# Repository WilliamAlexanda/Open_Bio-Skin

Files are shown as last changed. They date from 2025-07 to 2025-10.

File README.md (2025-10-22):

# Bio-Skin multi-modal tactile sensor

Nice to see you here!

This document will help you to know how to make your own Bio-Skin tactile sensor. If you still don't know what is Bio-Skin, please check our project homepage for more detail: https://williamalexanda.github.io/Bio-Skin/

## About the open source

Hardware of Bio-Skin will be open sourced under the Creative Commons Attribution-NonCommercial 4.0 International License, which means it's open for personal NonCommercial usage only.

Hardware parts include all molds, materials list and code for Esp32. Without software in PC, you can still get the sensor raw data by following this tutorial: https://youtu.be/GShOp8S6hr8

If you want the software which includes super-resolution or GUI or have any other questions, please send a email(haoran.guo@okstate.edu) to get more information.

中文制作教程：https://www.bilibili.com/video/BV1KD8Tz4ERr/
## Open Source List
Hardware folder: including all molds, Sensor PCB and single MUX PCB. All electronic components are directly marked in the figure.

Software folder: The code for ESP32-S3, which includes control, sample and data transmission function.

Material list: All the material you need to make the Bio-Skin.

## License

This project is released under a split licensing model to ensure both the hardware designs and the software code remain open and reciprocal.

| Component | License | Copyleft Strength | Full Text |
| :--- | :--- | :--- | :--- |
| **Hardware Designs** (Schematics, PCB, CAD files) | **CERN Open Hardware Licence v2.0 - Strongly Reciprocal (CERN-OHL-S 2.0)** | Strong | [LICENSE-HARDWARE](./LICENSE-HARDWARE) |
| **Software** (Firmware, Control Code) | **GNU Affero General Public License v3.0 (AGPLv3)** | Strong (Network Usage) | [LICENSE-SOFTWARE](./LICENSE-SOFTWARE) |

**CERN-OHL-S 2.0:** Requires that any modifications to the hardware design files must also be shared under the same license.

**AGPLv3:** Requires that any changes to the software, even if used only as a network service, must have their source code made available to users.

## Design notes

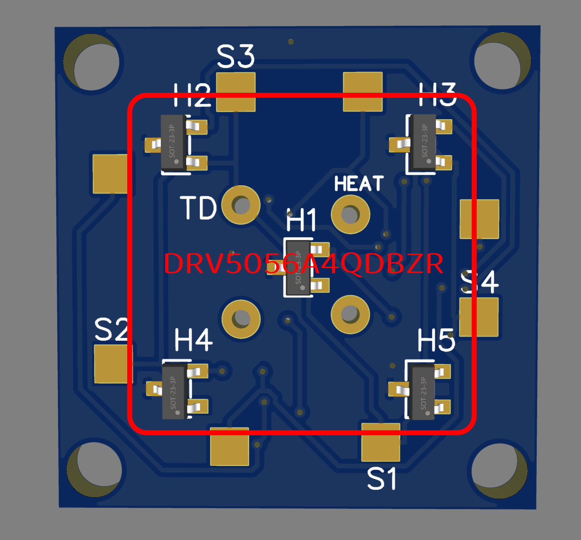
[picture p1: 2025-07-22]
Hardware/PCB/Main board/屏幕截图 2025-07-19 204715.jpg

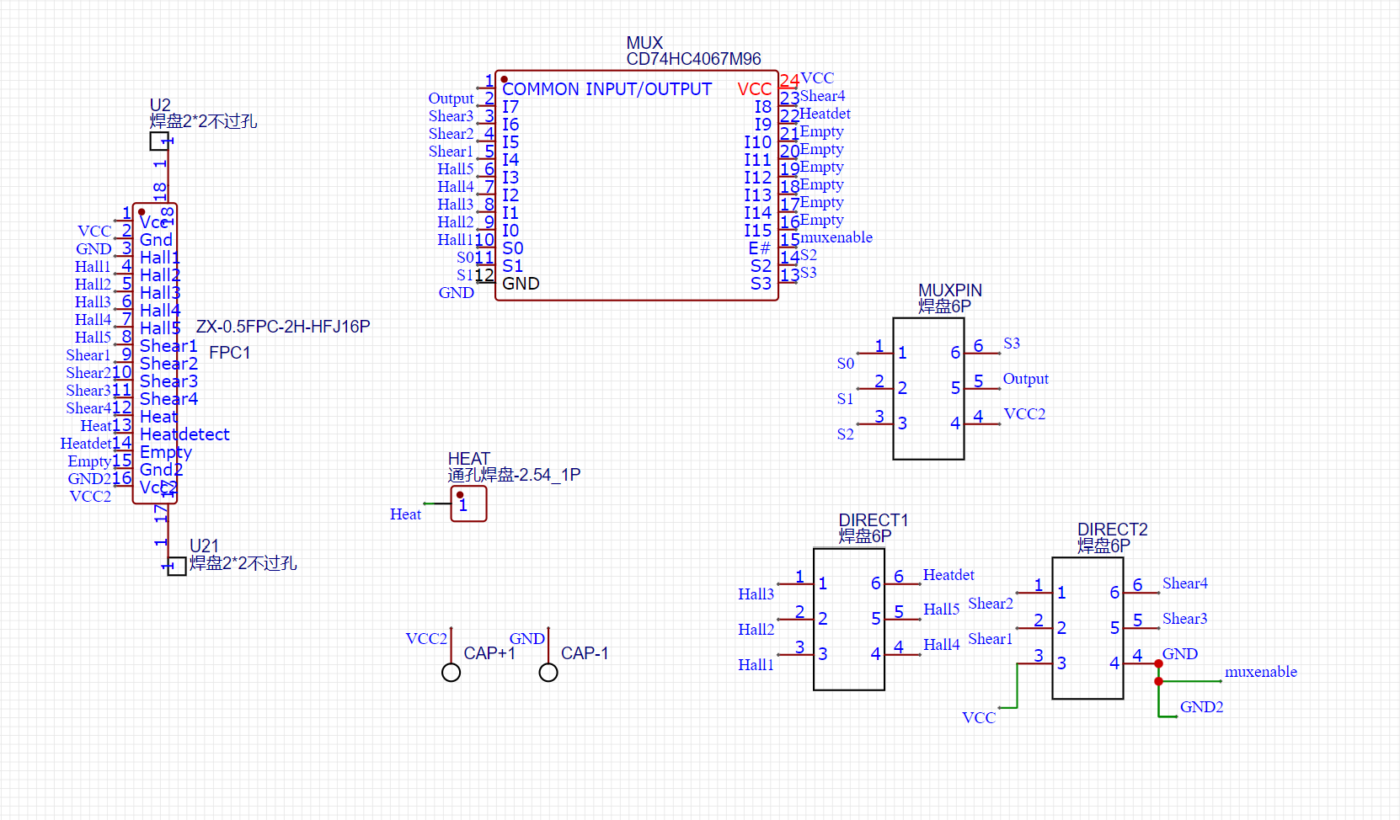
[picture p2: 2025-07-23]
Hardware/PCB/Little board/屏幕截图 2025-07-23 172235.png

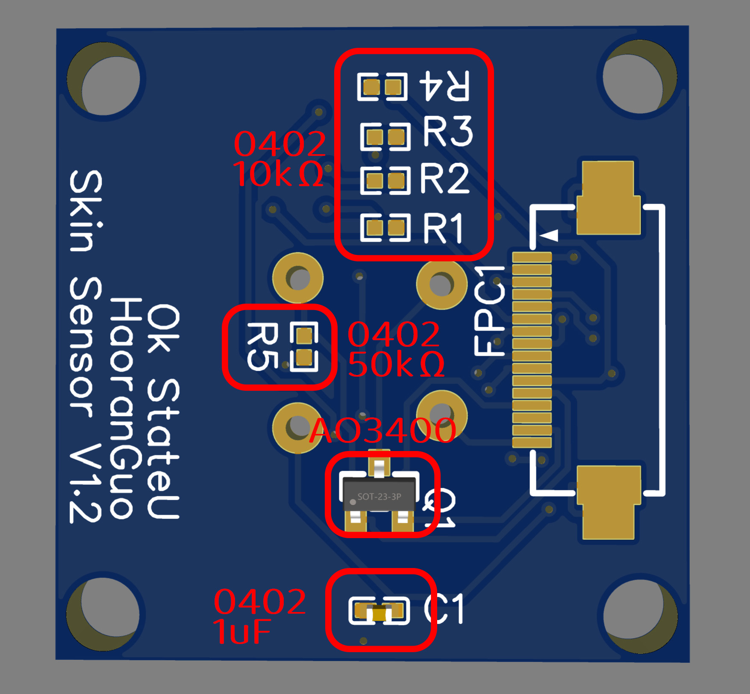
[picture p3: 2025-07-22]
Hardware/PCB/Main board/屏幕截图 2025-07-19 204727.jpg

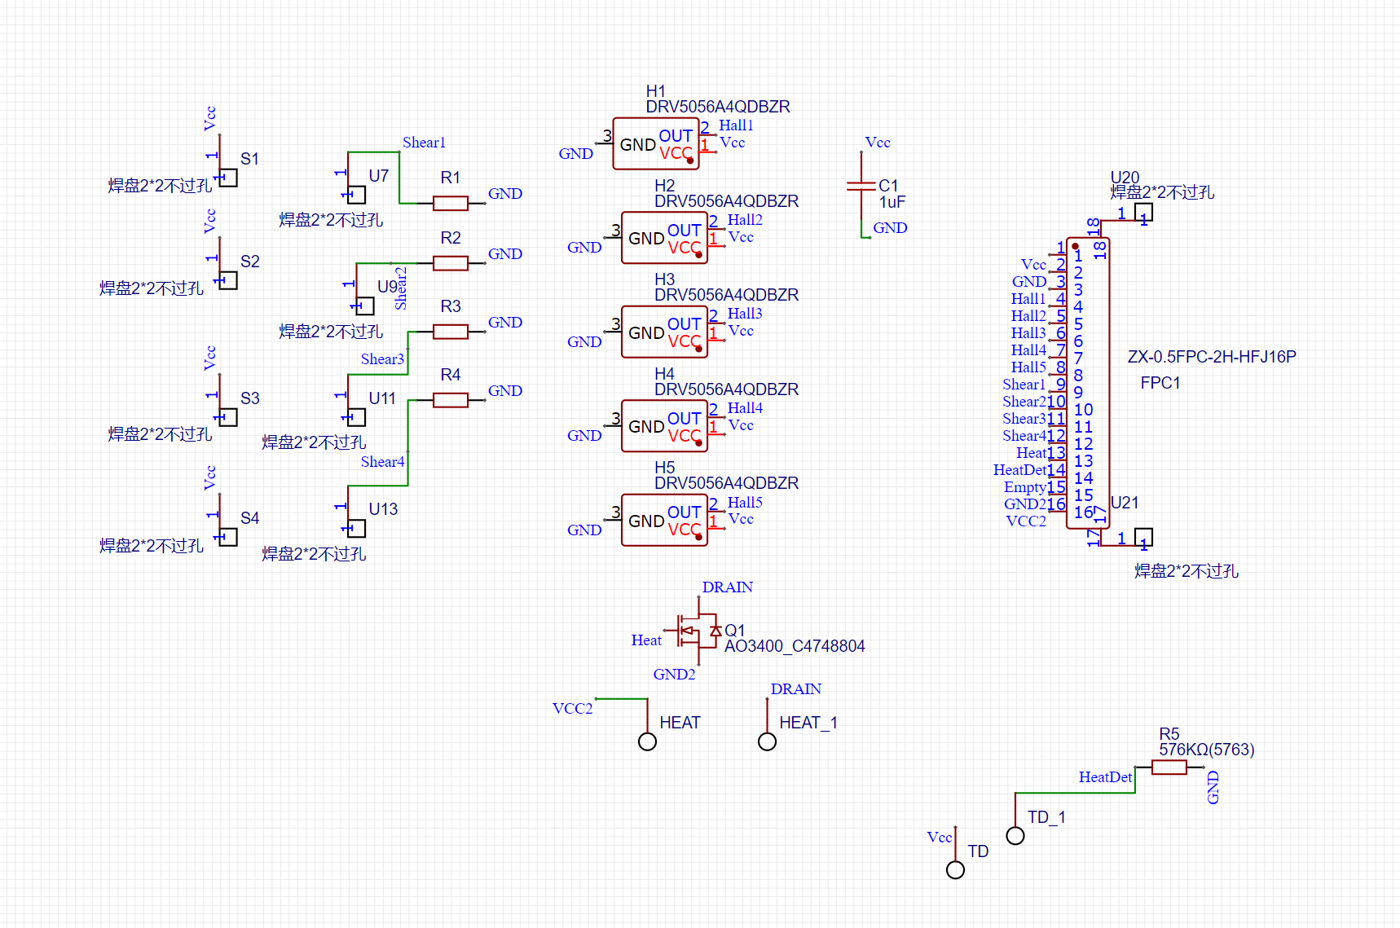
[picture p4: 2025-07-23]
Hardware/PCB/Main board/Design Sheet.png

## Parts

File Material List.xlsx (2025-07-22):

Name | Amount | type | price | discribe | Shop | Total | Link
PDMS-1 | 1 | Dragon Skin 10 Fast | 39.1 |  | Amazon | 39.1 | https://www.amazon.com/dp/B00IFI7G2E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
Hall-effect sensor | >=5 | DRV5056A4QDBZR | 0.22 |  | TEXAS Instrument |  | https://www.ti.com/product/DRV5056#params
meganetic | 1 | combo size | 9.99 |  | Amazon | 9.99 | https://www.amazon.com/TRYMAG-Magnets-Different-Miniatures-Refrigerator/dp/B0BLSLZ8JN?s=industrial
ESP32-S3 | >=1
Spring | >=4 |  |  | #VALUE!
Resistance Heating Coils Resistor Wire | 1 |  | 5.95 |  | Amazon | 5.95 | https://www.amazon.com/US-SA-AJD-144156-Nichrome-Resistance-Heating-Resistor/dp/B019MNNRN2?s=industrial
Pressure Sensitity film | 1 |  | 4.95 |  |  |  | https://www.adafruit.com/product/1361
Enameled Copper Wire | 1 |  | 12.29 |  | Amazon |  | https://www.amazon.com/BNTECHGO-AWG-Magnet-Wire-Transformers/dp/B07GBMKMKY?sp_csd=d2lkZ2V0TmFtZT1zcF9hdGY
NTC Thermistors Resistors | 1 |  | 11.99 |  | Amazon |  | https://www.amazon.com/KOKISO-Thermistors-Resistors-Temperature-Assortment/dp/B09LSCXN32
Conductive Nylon Conductive Adhesive Tape | 1 |  | 10 |  | Amazon |  | https://www.amazon.com/0-2in-Conductive-Nylon-Adhesive-Circuits/dp/B0BP1BNYR6?sp_csd=d2lkZ2V0TmFtZT1zcF9hdGY
FPC SLOT | >=5 | 16pin
FPC | >=1 | 16pin (opposite pin face)
0402 residtor | 1 |  | 7.99 |  |  |  | https://www.amazon.com/Yobett-3250PCS-Resistor-Tolerance-Resistors/dp/B0BZGQ8136
0402 capacitor | 1 | 1200pcs | 8.49 |  |  |  | https://www.amazon.com/Cermant-Capacitor-Assorted-1pF-10uF-Electronic/dp/B09V9WD8S6
Surgical Grade Blades | 1 |  | 6.99 |  |  |  | https://www.amazon.com/Surgical-Sterile-Practicing-Sculpting-Repairing/dp/B07WTVF64Z
TPS736 NMOS | >=1 |  | 5.19 |  |  |  | https://www.amazon.com/5PCS-TPS73601DBVT-TPS73601DBVR-TPS73601-SOT23-5/dp/B0CWTVX3QQ
CD74HC4067M96 | >=1 |  | 9.81 |  |  |  | https://www.amazon.com/CD74HC4067M96-HC4067M-multiplexer-Switch-SOP-24/dp/B0CSZB68L3
Dupong Wire | 1 | 20cm, male to female, 120pcs | 7.98 |  | amazon | 7.98 | https://www.amazon.com/EDGELEC-Breadboard-1pin-1pin-Connector-Multicolored/dp/B07GD1TFBR
Screw m2x4 | 1 | 100pcs | 7.76 |  | amazon | 7.76 | https://www.amazon.com/iexcell-Thread-Socket-Screws-Finish/dp/B0D4JM92FW

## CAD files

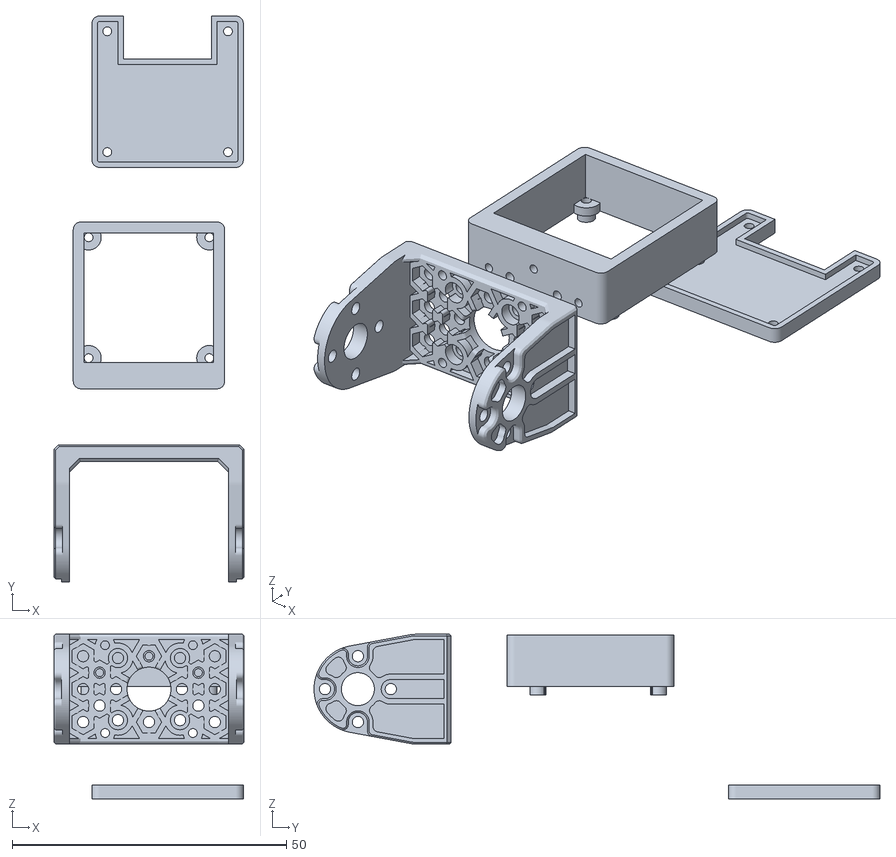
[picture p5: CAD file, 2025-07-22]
Hardware/Mold/Sensor frame.stl
34.6 x 103.1 x 30.0

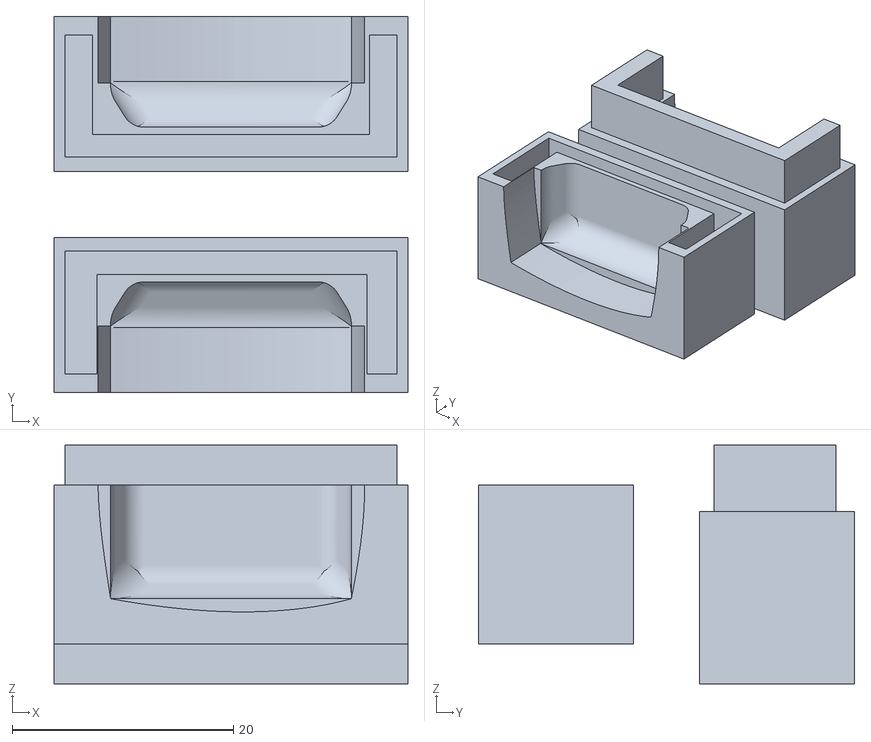
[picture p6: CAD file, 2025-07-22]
Hardware/Mold/Core mold-1.stl
32.0 x 34.0 x 21.6

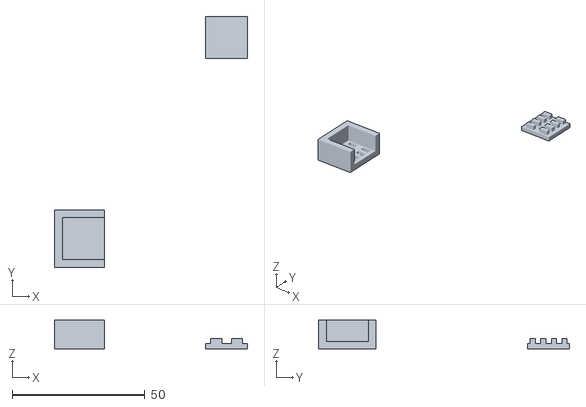
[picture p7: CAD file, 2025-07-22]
Hardware/Mold/Heating wire mold.stl
72.8 x 94.7 x 10.9

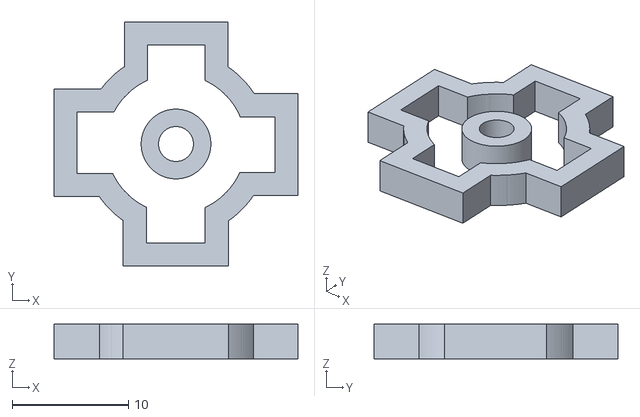
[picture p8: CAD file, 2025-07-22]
Hardware/Mold/Core mold-2.stl
21.0 x 21.0 x 3.00

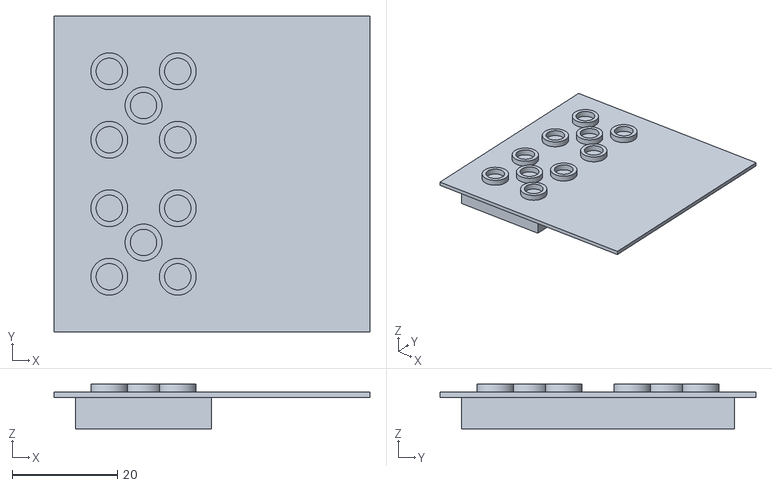
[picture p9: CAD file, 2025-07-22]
Hardware/Mold/Core mold-3.stl
60.0 x 60.0 x 8.50

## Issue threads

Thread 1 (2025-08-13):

Inquire about information related to PCB boards.

QLI037, 2025-08-13:
Hello, thank you so much for making these materials available open source. I would like to inquire about the setting of resistance values in main board. Are the resistance values of R1 to R4 in the main board 10kΩ? Because it is not written in the schematic diagram. Also, is the resistance value of R5 576kΩ or 50kΩ? The schematic diagram and the component diagram are different.

QLI037, 2025-08-16:
Thank you for your detailed answer!

Closed 2025-08-16.

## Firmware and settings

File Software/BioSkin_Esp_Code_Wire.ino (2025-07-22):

#include <Arduino.h>

// Pin Definitions
#define MUX_S0 1
#define MUX_S1 2
#define MUX_S2 3
#define MUX_S3 4
#define MUX_SIG 5 // Signal from MUX to ESP32-S3
#define MUX_EN 15 // MUX enable pin
#define HEATER_CTRL 6 // Heater control pin
#define STANDARD_SENSOR 10 // New standard sensor analog input

// Multiplexer control
uint8_t muxChannel[10] = {
  0b0000, 0b0001, 0b0010, 0b0011, 0b0100, 
  0b0101, 0b0110, 0b0111, 0b1000, 0b1001
};

// Sampling interval
const unsigned long samplingInterval = 5; // 10ms for 100Hz
const unsigned long heaterPeriod = 500; // 0.5 seconds in ms

unsigned long lastHeaterUpdate = 0;
int heaterDutyCycle = 0; // Duty cycle in percentage

void setup() {
  // Initialize Serial Monitor
  Serial.begin(250000);

  // Pin Modes
  pinMode(MUX_S0, OUTPUT);
  pinMode(MUX_S1, OUTPUT);
  pinMode(MUX_S2, OUTPUT);
  pinMode(MUX_S3, OUTPUT);
  pinMode(MUX_EN, OUTPUT);
  pinMode(HEATER_CTRL, OUTPUT);
  pinMode(MUX_SIG, INPUT);
  pinMode(STANDARD_SENSOR, INPUT); // Configure the standard sensor pin as input

  // Enable multiplexer
  digitalWrite(MUX_EN, LOW);
  // Turn off heater initially
  digitalWrite(HEATER_CTRL, LOW);

  // Set ADC characteristics
  analogReadResolution(12); // Set ADC resolution to 12 bits
  analogSetAttenuation(ADC_11db); // Set attenuation to measure full range (0 - 3.3V)
}

void loop() {
  // Array to store analog readings
  int readings[11]; // Adjusted size to include standard sensor data

  // Loop through each channel of the multiplexer
  for (int i = 0; i < 10; i++) {
    selectMuxChannel(i);
    delayMicroseconds(100); // Allow settling time (0.1ms)
    readings[i] = analogRead(MUX_SIG);
    if (i == 9) { // Check the temperature channel
      adjustHeater(readings[i]);
    }
  }

  // Read the standard sensor data
  readings[10] = analogRead(STANDARD_SENSOR);

  // Send data over Serial
  sendDataSerial(readings);

  // Wait for next sample
  delay(samplingInterval);
}

void selectMuxChannel(int channel) {
  digitalWrite(MUX_S0, bitRead(muxChannel[channel], 0));
  digitalWrite(MUX_S1, bitRead(muxChannel[channel], 1));
  digitalWrite(MUX_S2, bitRead(muxChannel[channel], 2));
  digitalWrite(MUX_S3, bitRead(muxChannel[channel], 3));
}

void sendDataSerial(int *readings) {
  char data[64];
  int len = 0;

  // Format data as a compact comma-separated string
  for (int i = 0; i < 11; i++) {
    len += snprintf(data + len, sizeof(data) - len, "%d", readings[i]);
    if (i < 10) {
      len += snprintf(data + len, sizeof(data) - len, ",");
    }
  }

  // Send data via Serial
  Serial.println(data);
}

void adjustHeater(int temperatureAdcValue) {
  if (temperatureAdcValue < 1100) {
    heaterDutyCycle = 100; // Maximum duty cycle
  } else if (temperatureAdcValue >= 1100 && temperatureAdcValue < 2050) {
    heaterDutyCycle = map(temperatureAdcValue, 1100, 2100, 100, 0); // Linearly decrease duty cycle
  } else {
    heaterDutyCycle = 0; // Turn off heater
  }

  unsigned long currentTime = millis();
  unsigned long onTime = heaterPeriod * heaterDutyCycle / 100;
  unsigned long offTime = heaterPeriod - onTime;

  if (heaterDutyCycle > 0 && currentTime - lastHeaterUpdate < onTime) {
    digitalWrite(HEATER_CTRL, HIGH); // Heater ON
  } else if (heaterDutyCycle > 0 && currentTime - lastHeaterUpdate >= onTime && currentTime - lastHeaterUpdate < heaterPeriod) {
    digitalWrite(HEATER_CTRL, LOW); // Heater OFF
  } else if (currentTime - lastHeaterUpdate >= heaterPeriod) {
    lastHeaterUpdate = currentTime; // Reset the cycle
  }
}
